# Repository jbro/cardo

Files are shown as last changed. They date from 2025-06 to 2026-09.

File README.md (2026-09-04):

# Cardo Keyboard

This is a custom ergonomic wireless keyboard. The design language is based on the [Reviung41](https://github.com/gtips/reviung/tree/master) and the key layout is based on the [Atreus](https://atreus.technomancy.us/) keyboard without thumb keys.

## Features

- Columnar layout
- Low profile
  - Kailh Choc V1 switches
- Sub 40% layout
  - 36 1u keys
  - 1.5u space bar
- Wireless connectivity
- Low part count
  - No diodes
  - Shift register based with a single column
  - Mostly SMD components
- Seeed XIAO nrf52840 micro controller
- 3D printable case (TBD)

## Keymap

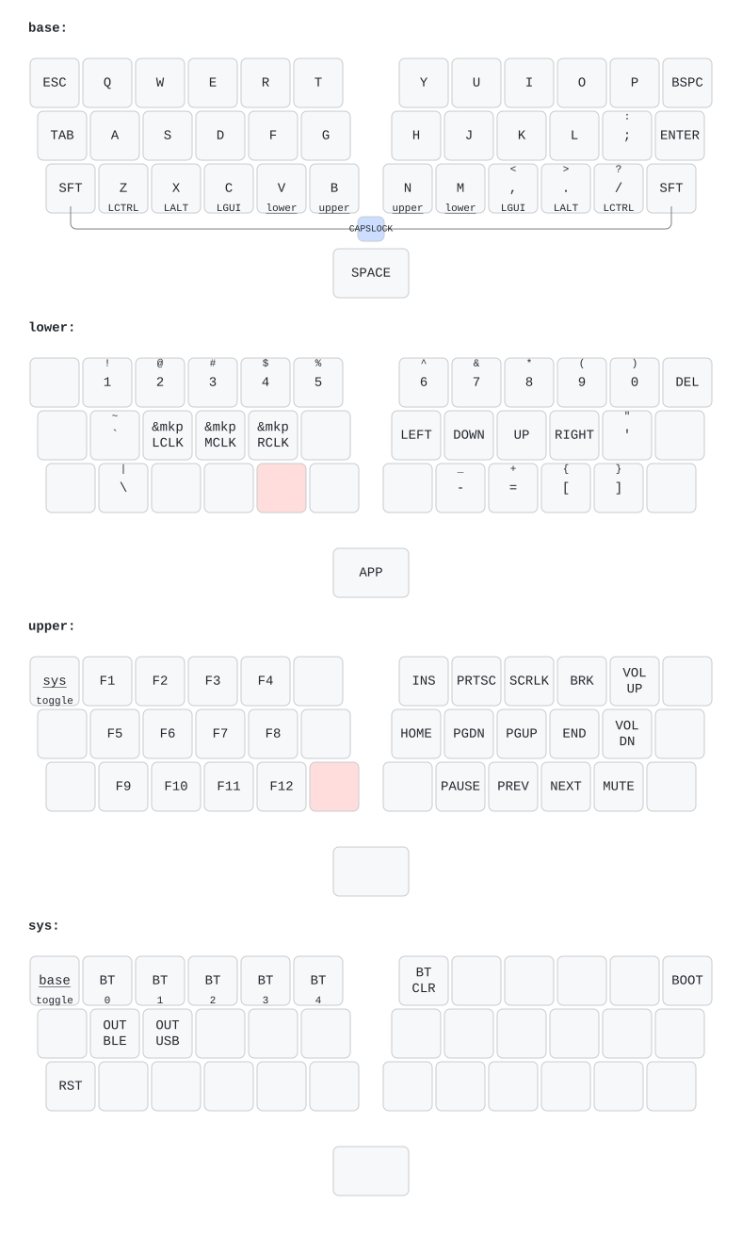
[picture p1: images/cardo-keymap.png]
keymap


## Schematics

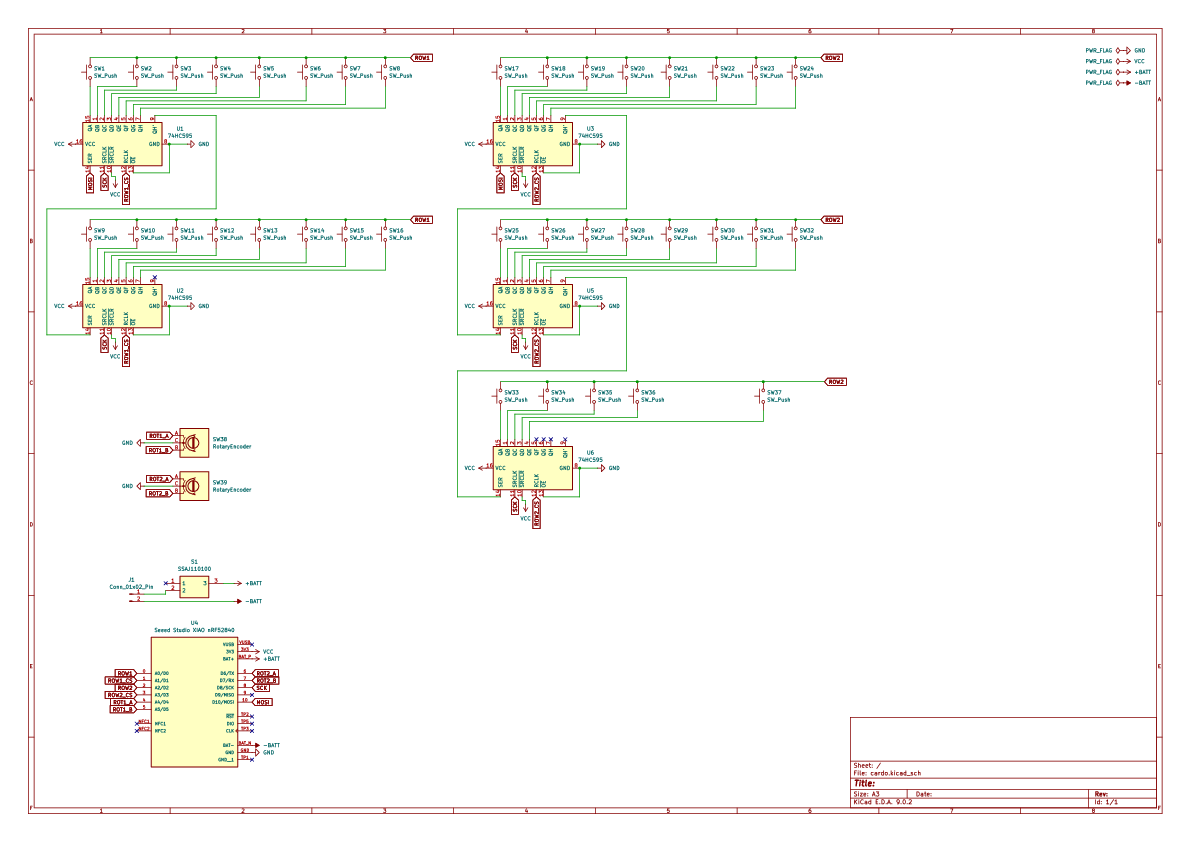
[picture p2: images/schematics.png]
schematics


## PCB

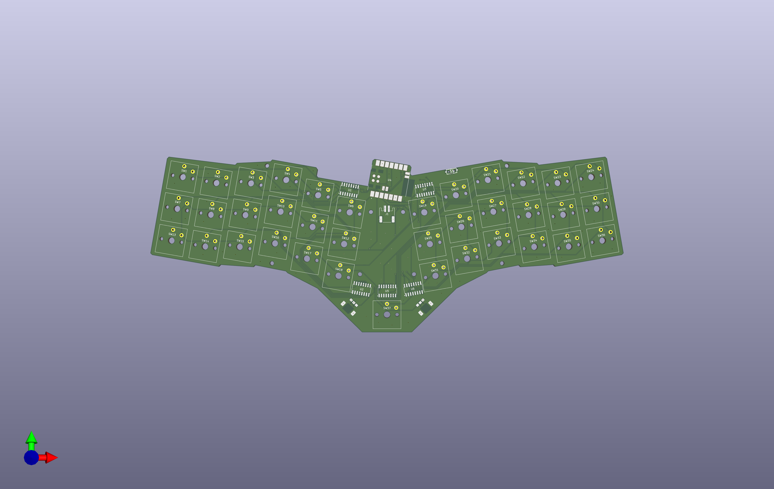
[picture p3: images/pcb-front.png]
PCB front

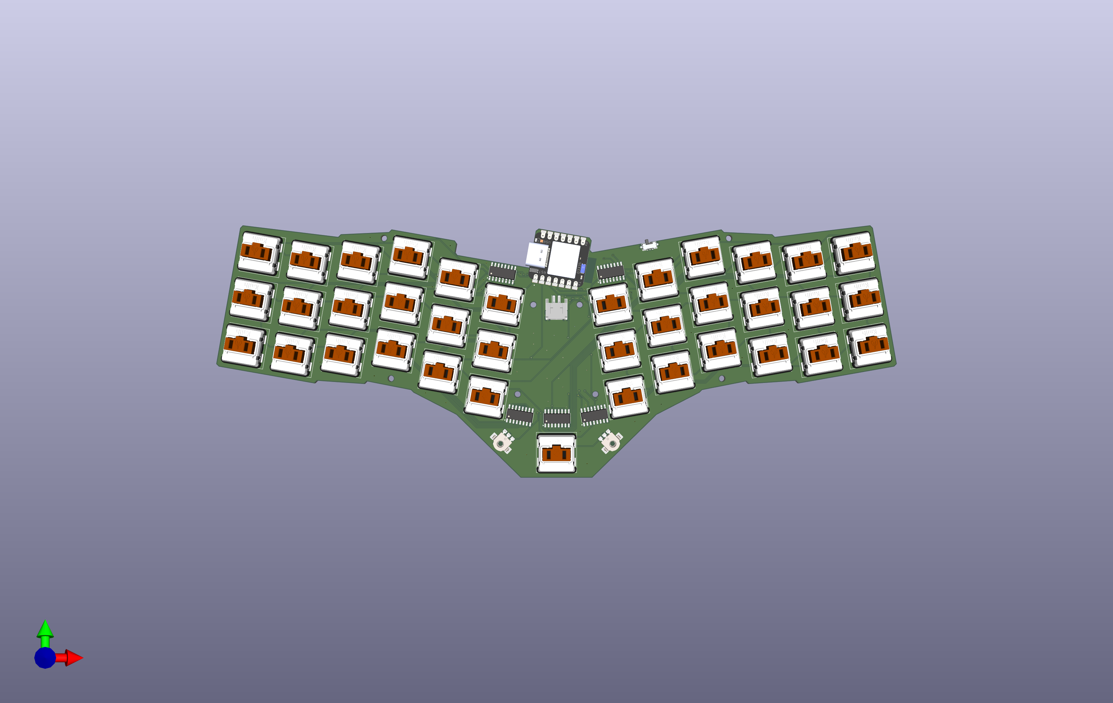
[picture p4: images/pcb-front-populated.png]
PCB front populated

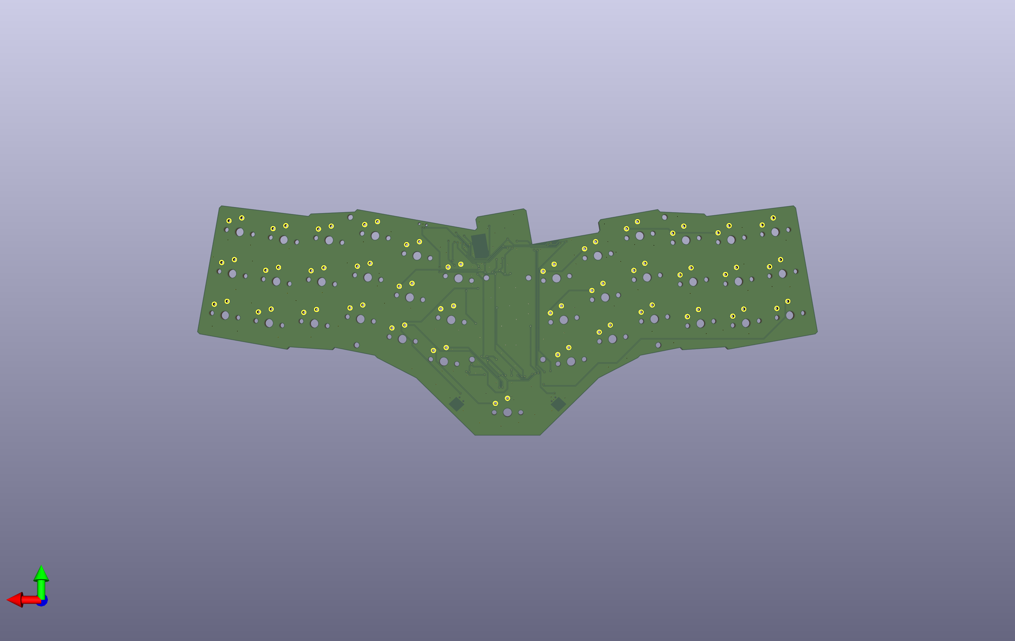
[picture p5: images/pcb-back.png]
PCB back


[3d model](https://github.com/jbro/cardo/blob/main/images/cardo.stl)

## BOM

| Part | Quantity | Description | Link |
| ---- | --- | --- | ---- |
| S2B-PH-SM4-TB(LF)(SN) | 1 | JST PH2 connector | [Mouser](https://www.mouser.dk/ProductDetail/306-S2BPHSM4TBLFSN) |
| SSAJ110100 | 1 | Slide switch | [Mouser](https://www.mouser.dk/ProductDetail/688-SSAJ110100) |
| 7305-0-15-15-47-27-10-0 | 74 | Mill Max 7305 "hot swap" socket | [Mouser](https://www.mouser.dk/ProductDetail/575-7305015154727100) |
| EC05E1220401 | 2 | Rotary encoder | [Mouser](https://www.mouser.dk/ProductDetail/688-EC05E1220401) |
| SN74HC595DR | 5 | 74HC595 shift register | [Mouser](https://www.mouser.dk/ProductDetail/595-SN74HC595DR) |
| 102010448 | 1 | Seeed XIAO nrf52840 | [Mouser](https://www.mouser.dk/ProductDetail/713-102010448) or  [Seeed studio](https://www.seeedstudio.com/Seeed-XIAO-BLE-nRF52840-p-5201.html) |
| LPR-CHC-SNS-010 | 37 | Kailh Choc Sunset tactile V1 switches | [Splitkb](https://splitkb.com/products/sunset-kailh-low-profile-choc-switches?variant=42742153871619) |
| KSM-MGG-1UN-010 | 34 | 1u MBK PBT Coloured Blank Keycaps | [Splitkb](https://splitkb.com/products/mbk-pbt-coloured-blank-keycaps?variant=49589854011739) |
| KSM-MGG-1UH-002 | 2 | 1u MBK PBT Coloured Blank Keycaps (Homing) | [Splitkb](https://splitkb.com/products/mbk-pbt-coloured-blank-keycaps?variant=49589854404955) |
| KSM-MGG-1U5-002 | 1 | 1.5u MBK PBT Coloured Blank Keycap | [Splitkb](https://splitkb.com/products/mbk-pbt-coloured-blank-keycaps?variant=49589855977819) |
| AM3144y | 1 | Li-Pol battery 60mAh, 3.7V, 501015 | [Ampul](https://ampul.eu/en/battery/4453-li-pol-battery-60mah-37v-501015) |

## License

This project is licensed under the [Unlicense](https://unlicense.org/). Feel free to use, modify, and distribute this project as you wish.

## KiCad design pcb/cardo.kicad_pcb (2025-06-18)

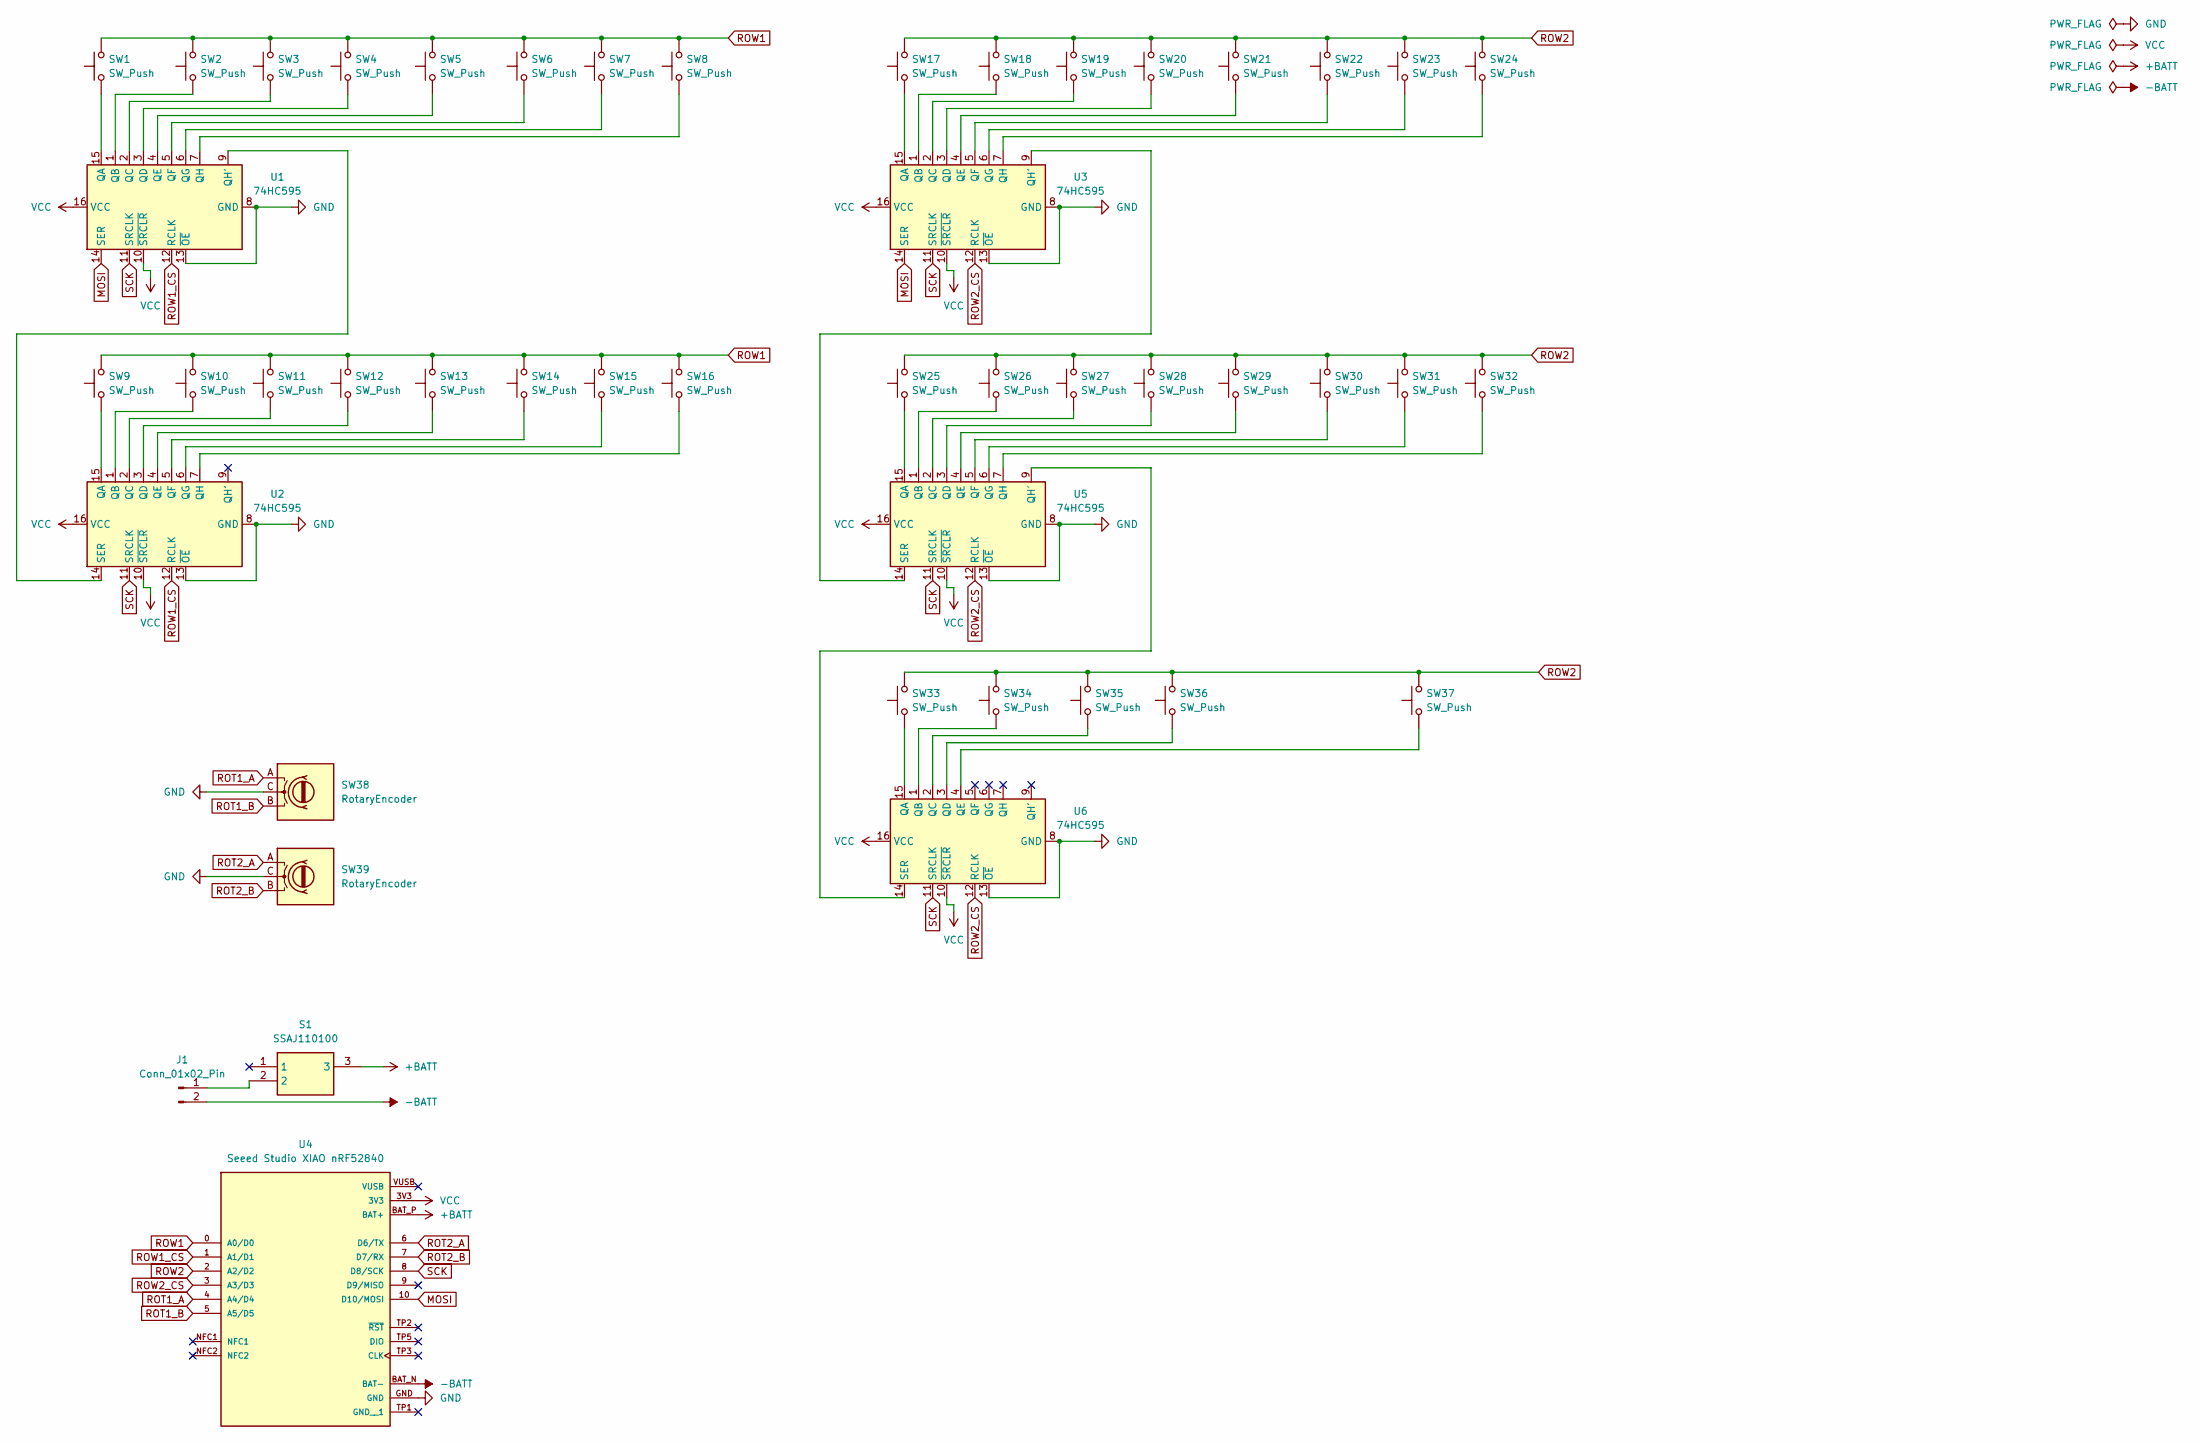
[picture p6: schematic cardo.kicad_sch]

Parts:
J1: Conn_01x02_Pin; JST_PH_S2B-PH-SM4-TB_1x02-1MP_P2.00mm_Horizontal
S1: SSAJ110100; SSAJ110100_1; Mouser Part Number 688-SSAJ110100
SW1, SW2, SW3, SW4, SW5, SW6, SW7, SW8, SW9, SW10, SW11, SW12, SW13, SW14, SW15, SW16, SW17, SW18, SW19, SW20, SW21, SW22, SW23, SW24, SW25, SW26, SW27, SW28, SW29, SW30, SW31, SW32, SW33, SW34, SW35, SW36: SW_Push; SW_Kailh_Choc_V1_1.00u
SW37: SW_Push; SW_Kailh_Choc_V1_1.50u
SW38, SW39: RotaryEncoder; Alps EC05E1220401
U1, U2, U3, U5, U6: 74HC595; SOIC-16_3.9x9.9mm_P1.27mm
U4: Seeed Studio XIAO nRF52840; PARTREV 2022/08/18

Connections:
+BATT: S1.3, U4.BAT_P (BAT+)
-BATT: J1.2, U4.BAT_N (BAT-)
GND: J1.MP, S1.4, S1.5, SW38.C, SW38.MP, SW39.C, SW39.MP, U1.8 (GND), U1.13 (~OE), U2.8 (GND), U2.13 (~OE), U3.8 (GND), U3.13 (~OE), U4.GND, U5.8 (GND), U5.13 (~OE), U6.8 (GND), U6.13 (~OE)
MOSI: U1.14 (SER), U3.14 (SER), U4.10 (D10/MOSI)
unnamed: J1.1, S1.2
unnamed: SW1.1, U1.15 (QA)
unnamed: SW2.1, U1.1 (QB)
unnamed: SW3.1, U1.2 (QC)
unnamed: SW4.1, U1.3 (QD)
unnamed: SW5.1, U1.4 (QE)
unnamed: SW6.1, U1.5 (QF)
unnamed: SW7.1, U1.6 (QG)
unnamed: U1.9 (QH'), U2.14 (SER)
unnamed: SW8.1, U1.7 (QH)
unnamed: SW9.1, U2.15 (QA)
unnamed: SW10.1, U2.1 (QB)
unnamed: SW11.1, U2.2 (QC)
unnamed: SW12.1, U2.3 (QD)
unnamed: SW13.1, U2.4 (QE)
unnamed: SW14.1, U2.5 (QF)
unnamed: SW15.1, U2.6 (QG)
unnamed: SW16.1, U2.7 (QH)
unnamed: SW17.1, U3.15 (QA)
unnamed: SW18.1, U3.1 (QB)
unnamed: SW19.1, U3.2 (QC)
unnamed: SW20.1, U3.3 (QD)
unnamed: SW21.1, U3.4 (QE)
unnamed: SW22.1, U3.5 (QF)
unnamed: SW23.1, U3.6 (QG)
unnamed: U3.9 (QH'), U5.14 (SER)
unnamed: SW24.1, U3.7 (QH)
unnamed: SW25.1, U5.15 (QA)
unnamed: SW26.1, U5.1 (QB)
unnamed: SW27.1, U5.2 (QC)
unnamed: SW28.1, U5.3 (QD)
unnamed: SW29.1, U5.4 (QE)
unnamed: SW30.1, U5.5 (QF)
unnamed: SW31.1, U5.6 (QG)
unnamed: U5.9 (QH'), U6.14 (SER)
unnamed: SW32.1, U5.7 (QH)
unnamed: SW33.1, U6.15 (QA)
unnamed: SW34.1, U6.1 (QB)
unnamed: SW35.1, U6.2 (QC)
unnamed: SW36.1, U6.3 (QD)
unnamed: SW37.1, U6.4 (QE)
ROT1_A: SW38.A, U4.4 (A4/D4)
ROT1_B: SW38.B, U4.5 (A5/D5)
ROT2_A: SW39.A, U4.6 (D6/TX)
ROT2_B: SW39.B, U4.7 (D7/RX)
ROW1: SW1.2, SW2.2, SW3.2, SW4.2, SW5.2, SW6.2, SW7.2, SW8.2, SW9.2, SW10.2, SW11.2, SW12.2, SW13.2, SW14.2, SW15.2, SW16.2, U4.0 (A0/D0)
ROW1_CS: U1.12 (RCLK), U2.12 (RCLK), U4.1 (A1/D1)
ROW2: SW17.2, SW18.2, SW19.2, SW20.2, SW21.2, SW22.2, SW23.2, SW24.2, SW25.2, SW26.2, SW27.2, SW28.2, SW29.2, SW30.2, SW31.2, SW32.2, SW33.2, SW34.2, SW35.2, SW36.2, SW37.2, U4.2 (A2/D2)
ROW2_CS: U3.12 (RCLK), U4.3 (A3/D3), U5.12 (RCLK), U6.12 (RCLK)
SCK: U1.11 (SRCLK), U2.11 (SRCLK), U3.11 (SRCLK), U4.8 (D8/SCK), U5.11 (SRCLK), U6.11 (SRCLK)
VCC: U1.10 (~SRCLR), U1.16 (VCC), U2.10 (~SRCLR), U2.16 (VCC), U3.10 (~SRCLR), U3.16 (VCC), U4.3V3, U5.10 (~SRCLR), U5.16 (VCC), U6.10 (~SRCLR), U6.16 (VCC)

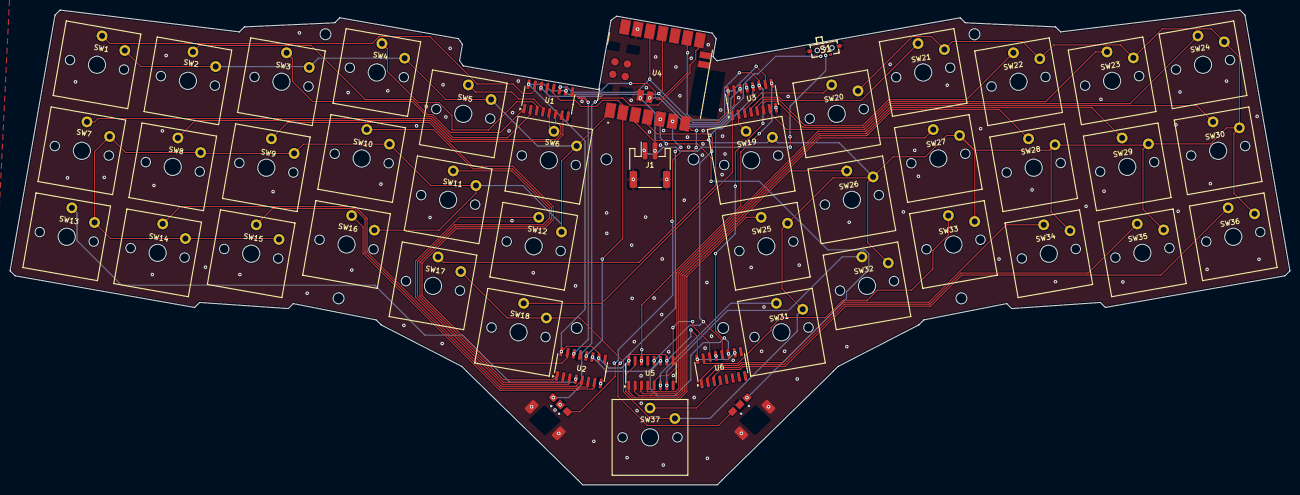
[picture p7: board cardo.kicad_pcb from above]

Board: 2 copper layers, 256.8 x 95.3 mm, 47 parts (0 on the bottom side), 55 nets.

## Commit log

2025-06-18 Add BOM
2025-06-18 Update BOM
    - Switches
    - Key caps
    - Battery
2025-06-18 Fix schematic image and update description
2026-09-03 Improve Bluetooth persistence and idle power use
2026-09-03 Ignore KiCad history
2026-09-04 Add mouse controls and encoder layer bindings
